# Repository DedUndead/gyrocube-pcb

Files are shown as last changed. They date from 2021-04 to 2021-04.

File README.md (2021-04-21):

# Gyrocube PCB design

Project is ongoing.

## Concept description 

GyroCube is a Smart-Home accessory. The GyroCube is a multipurpose cube that can perform different functions based on the cube placing. The functionality is changed by simply flipping the cube on the table. The functionalities are humidity measurements, OMA notifications, and weather-forecasts. GyroCube uses vibration modules and LEDs as the output method to notify the user of changes.<br><br>
GyroCube consists of the main station and cubes that will be in constant M2M communication. The main station handles the sensor measurements and internet communications, while the cubes react to changes in the main station. Thus, allowing the GyroCube environment to be scalable, as the user can connect as many cubes as he wants. 
The goal is to provide the user with a delightful-looking home accessory, which will also allow them to obtain helpful information in a simple, minimalistic way. 

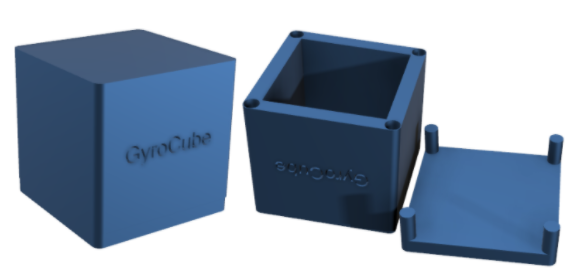
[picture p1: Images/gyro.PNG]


## Topology example - Star

The HUB acts as Zigbee coordinator/router, while the cubes are end devices of the topology. HUB communicates with Wireless Access Point.

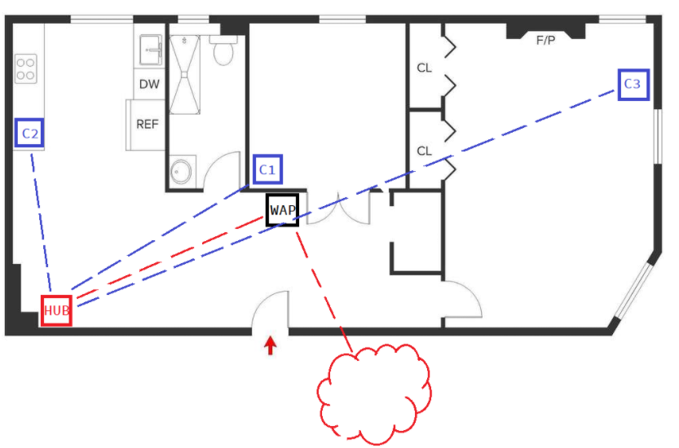
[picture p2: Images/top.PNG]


## PCB design description

PCB design for the gyrocube IoT project. Consists of several parts: x6 RGB LED PCBs, cube's MCU and main hub's MCU.
External components were used when designing the schematics

<b>Hub PCB</b>:<br>
[Microcontroller](https://app.ultralibrarian.com/details/23afb9f1-10a0-11e9-ab3a-0a3560a4cccc/Microchip/PIC32MX575F512H-80I-PT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)<br>
[RF Tranciever (Zigbee)](https://app.ultralibrarian.com/details/42fe3879-10a0-11e9-ab3a-0a3560a4cccc/Microchip/AT86RF231-ZU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)<br>
[Wi-Fi Module](https://app.ultralibrarian.com/details/2b6afdaf-b24e-11ea-b5d0-0aebb021a1ea/Silicon-Labs/WFM200S022XNA2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)

<b>Cube MCU</b>:<br>
[Microcontroller](https://app.ultralibrarian.com/details/4b4afbe8-2e28-11eb-9033-0a34d6323d74/Microchip/PIC18F47K40-I-P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)<br>
[Gyroscope](https://app.ultralibrarian.com/details/68dbfc0c-1e52-11eb-9033-0a34d6323d74/STMicroelectronics/L3GD20H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)<br>
Humidity/Temperature sensor is custom. The library is cached in the respective folder.<br>
[Vibration coin](https://www.snapeda.com/parts/C0720B001F/Jinlong%20Machinery%20&amp;%20Electronics,%20Inc./view-part/)

## LED PCB design:

Uses ws2812b-5050 LED and 100-1000 uF filtering capacitor. The exact value is not yet specified.

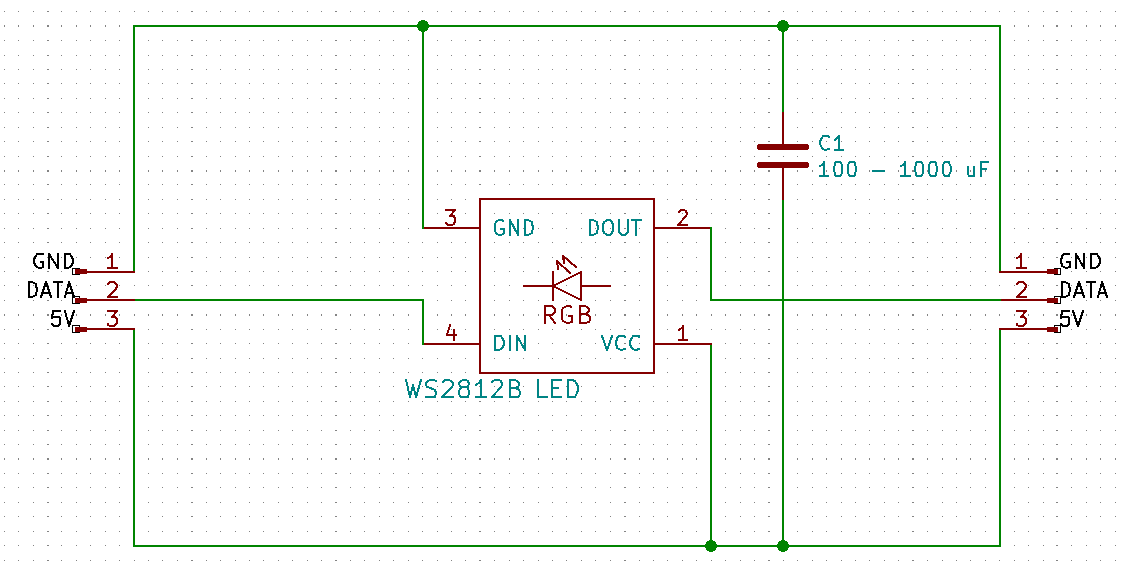
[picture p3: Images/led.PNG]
LED PCB


The LED PCB are connected to each other with wires. The cube's PCB contains the connector to connect the first LED, that starts the series.

Connector

## Cube PCB design:

Cube PCB contains the MCU and all the peripherals.

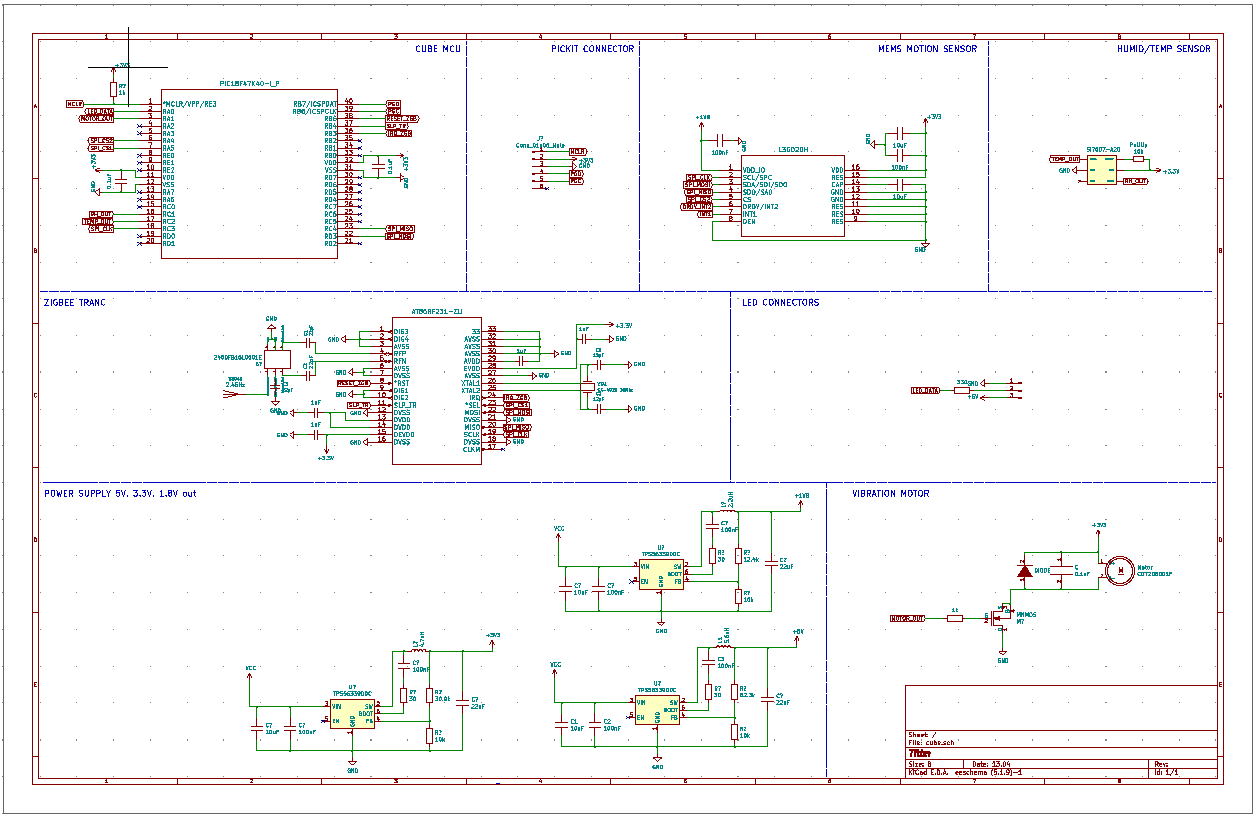
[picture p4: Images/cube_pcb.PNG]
Cube PCB


### Cube MCU: PIC18F47K40-I/P

The MCU consists of several connection "zones": 

* SPI communication with 2 chip select slave pins 
* MCLR/PDG/PGC + Connector for PICKit programmability
* Decoupling 0.1uF capacitors
* Peripheral control pins (PWM, sleep/wake up/reset signals)

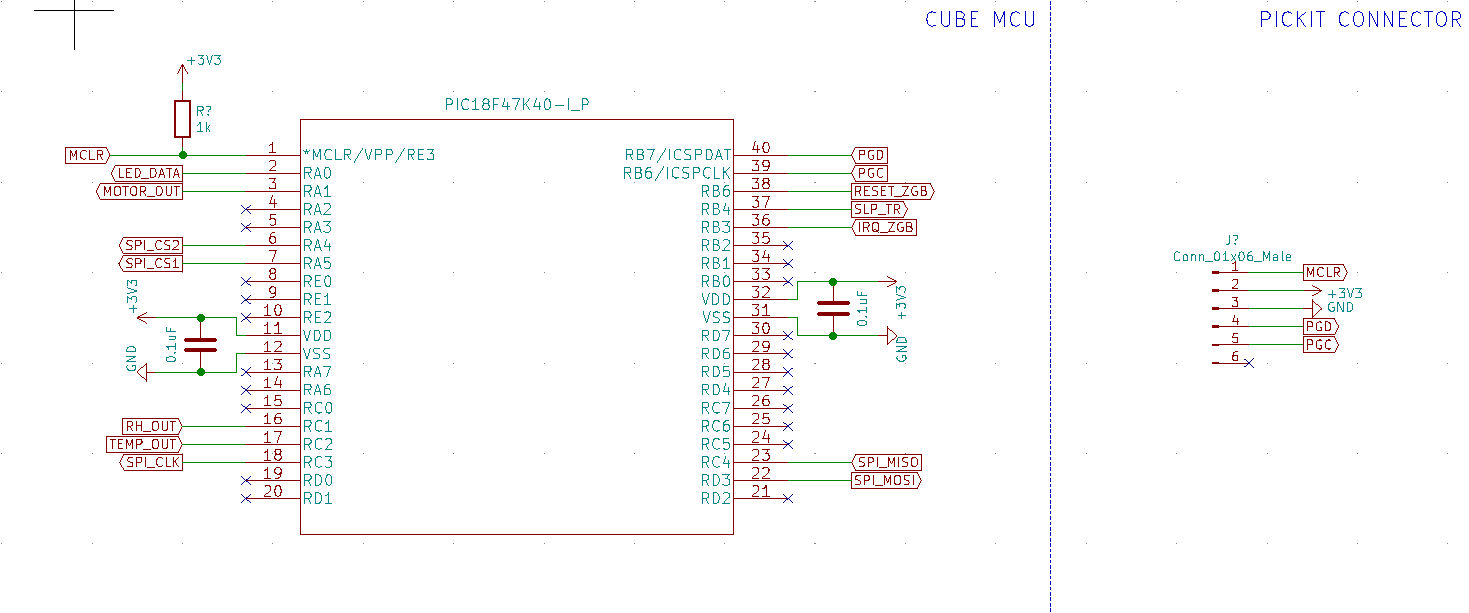
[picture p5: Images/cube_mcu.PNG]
Cube MCU


### Gyroscope and Temp/Hum sensor

MEMS Motion sensor: L3GD20H, three-axis gyroscope, utilizes SPI interface<br>
Humidity/Temperature  sensor: Si7007-A20, digital output via PWM

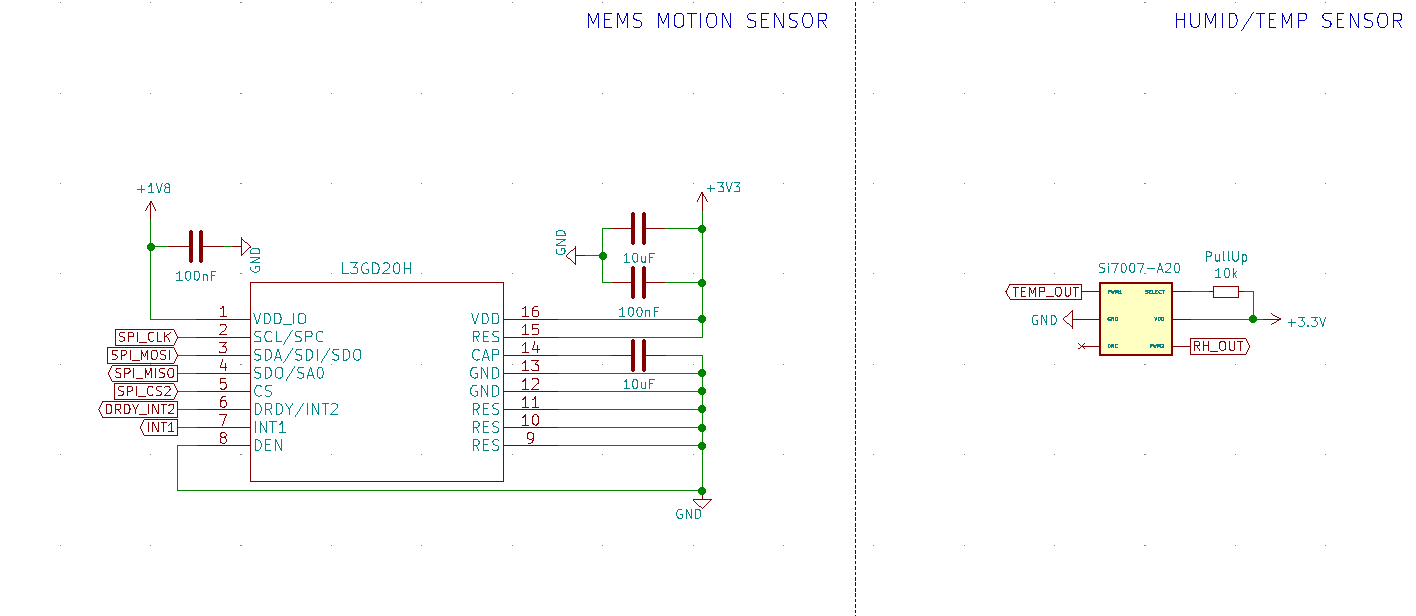
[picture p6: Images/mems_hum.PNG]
MEMS Motion and Temp


### Vibration motor

Diode and capacitor protect the components from voltage spikes, generated by the motor.<br>
Motor requires 75 mA, N-Channel MOSFET amplifies the current from MCU's GPIO.<br>
Intensity of vibration is handeled by PWM.

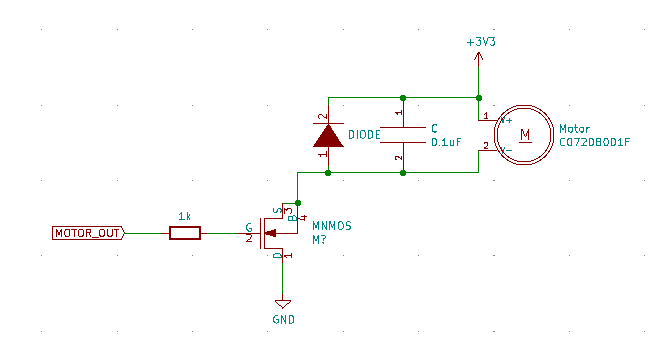
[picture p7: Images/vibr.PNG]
Vibration motor


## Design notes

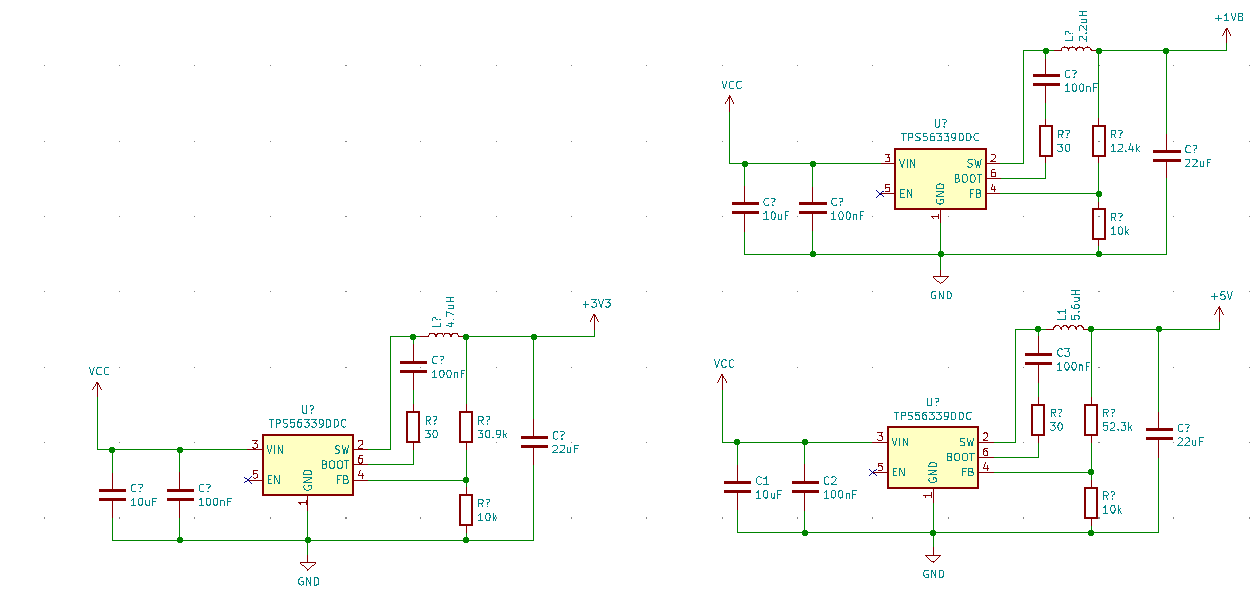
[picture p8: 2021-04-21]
Images/power_supply.PNG

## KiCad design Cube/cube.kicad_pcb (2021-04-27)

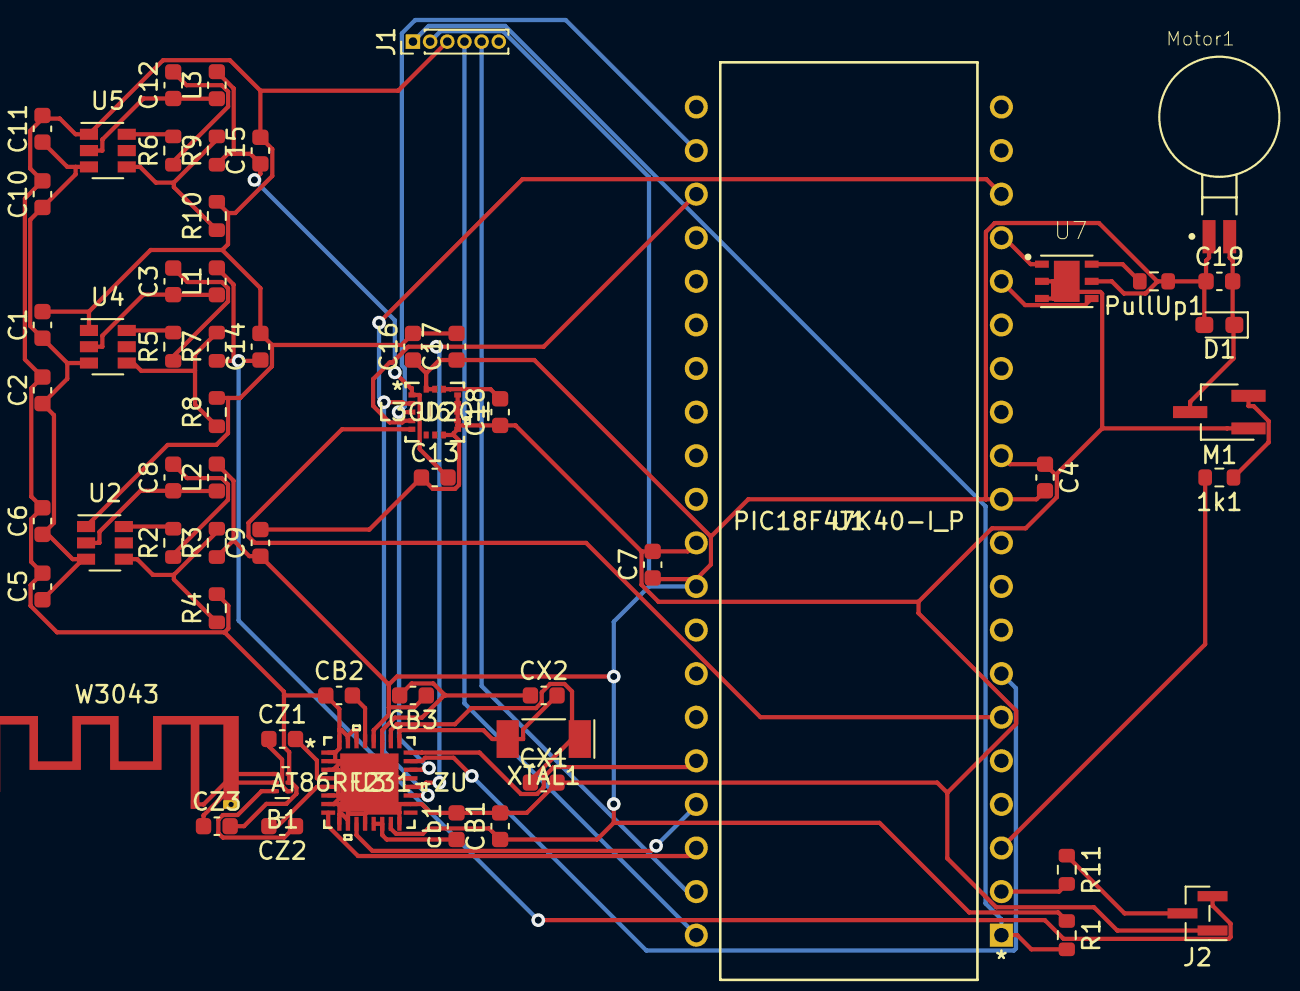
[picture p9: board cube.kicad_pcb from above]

Board: 2 copper layers, 59 parts (0 on the bottom side), 47 nets.

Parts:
1k1: R; R_0603_1608Metric
B1: 2450FB15L0001E; Balun_Johanson_1.6x0.8mm
C1, C5, C10, C16, C18: 10uF; C_0603_1608Metric
C2, C3, C6, C8, C11, C12, C13, C17: 100nF; C_0603_1608Metric
C4, C7, C19: 0.1uF; C_0603_1608Metric
C9, C14, C15: 22uF; C_0603_1608Metric
CB1, CB2, CB3: 1uF; C_0603_1608Metric
CX1, CX2: 12pF; C_0603_1608Metric
CZ1, CZ2, CZ3: 22pF; C_0603_1608Metric
D1: DIODE; D_0603_1608Metric_Pad1.05x0.95mm_HandSolder
J1: Conn_01x06_Male; PinHeader_1x06_P1.00mm_Vertical
J2: Conn_01x03_Male; PinHeader_1x03_P1.00mm_Vertical_SMD_Pin1Left
L1: 5.6uH; L_0603_1608Metric
L2: 4.7uH; L_0603_1608Metric
L3: 2.2uH; L_0603_1608Metric
M1: MNMOS; SOT-23W_Handsoldering
Motor1: C0720B001F; XDCR_C0720B001F
PullUp1: 10k; R_0603_1608Metric
R1: 1k; R_0603_1608Metric
R2, R5, R6: 30; R_0603_1608Metric
R3: 30.9k; R_0603_1608Metric
R4, R8, R10: 10k; R_0603_1608Metric
R7: 52.3k; R_0603_1608Metric
R9: 12.4k; R_0603_1608Metric
R11: 330; R_0603_1608Metric
U1: PIC18F47K40-I_P; PIC18F47K40-I&slash_P
U2, U4, U5: TPS56339DDC; SOT-23-6
U3: AT86RF231-ZU
U6: L3GD20H
U7: Si7007-A20; SON100P300X300X80-7N
W3043: 2.4GHz; Texas_SWRA117D_2.4GHz_Left
XTAL1: CX-4025 16Mhz; Crystal_SMD_MicroCrystal_CC4V-T1A-2Pin_5.0x1.9mm
cb1: 1uF; C_0603_1608Metric

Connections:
+1V8: C13.2, C15.1, L3.2, R9.1, U6.1
+3V3: C4.2, C7.1, C9.1, C16.1, C17.1, C19.1, CB1.1, CB3.1, D1.2, J1.2, L2.2, Motor1.1, PullUp1.1, R1.1, R3.1, U1.11, U1.32, U3.15, U3.28, U6.15, U6.16, U7.5
+5V: C14.1, J2.3, L1.2, R7.1
GND: B1.5, B1.6, C1.2, C2.2, C4.1, C5.2, C6.2, C7.2, C9.2, C10.2, C11.2, C13.1, C14.2, C15.2, C16.2, C17.2, C18.1, CB1.2, CB2.1, CB3.2, CX1.2, CX2.1, CZ3.2, J1.3, J2.1, M1.1, R4.2, R8.2, R10.2, U1.12, U1.31, U2.1, U3.1, U3.2, U3.3, U3.6, U3.7, U3.9, U3.10, U3.12, U3.16, U3.18, U3.21, U3.27, U3.30, U3.31, U3.32, U3.33, U4.1, U5.1, U6.8, U6.9, U6.10, U6.11, U6.12, U6.13, U7.2, U7.3, U7.7, cb1.2
IRQ_ZGB: U1.36, U3.24
LED_DATA: R11.2, U1.2
MCLR: J1.1, R1.2, U1.1
MOTOR_OUT: 1k1.2, U1.3
unnamed: 1k1.1, M1.2
unnamed: B1.1, W3043.1
unnamed: B1.2, CZ3.1
unnamed: B1.3, CZ2.1
unnamed: B1.4, CZ1.1
unnamed: C3.1, L1.1, U4.2
unnamed: C3.2, R5.1
unnamed: C8.1, L2.1, U2.2
unnamed: C8.2, R2.1
unnamed: C12.1, L3.1, U5.2
unnamed: C12.2, R6.1
unnamed: C18.2, U6.14
unnamed: C19.2, D1.1, M1.3, Motor1.2
unnamed: CB2.2, U3.29
unnamed: CX1.1, U3.26, XTAL1.1
unnamed: CX2.2, U3.25, XTAL1.2
unnamed: CZ1.2, U3.4
unnamed: CZ2.2, U3.5
unnamed: J2.2, R11.1
unnamed: PullUp1.2, U7.6
unnamed: R2.2, U2.6
unnamed: R3.2, R4.1, U2.4
unnamed: R5.2, U4.6
unnamed: R6.2, U5.6
unnamed: R7.2, R8.1, U4.4
unnamed: R9.2, R10.1, U5.4
unnamed: U3.13, U3.14, cb1.1
PGC: J1.5, U1.39
PGD: J1.4, U1.40
RESET_ZGB: U1.38, U3.8
RH_OUT: U1.16, U7.4
SLP_TR: U1.37, U3.11
SPI_CLK: U1.18, U3.19, U6.2
SPI_CS1: U1.7, U3.23
SPI_CS2: U1.6, U6.5
SPI_MISO: U1.23, U3.20, U6.4
SPI_MOSI: U1.22, U3.22, U6.3
TEMP_OUT: U1.17, U7.1
VCC: C1.1, C2.1, C5.1, C6.1, C10.1, C11.1, U2.3, U4.3, U5.3

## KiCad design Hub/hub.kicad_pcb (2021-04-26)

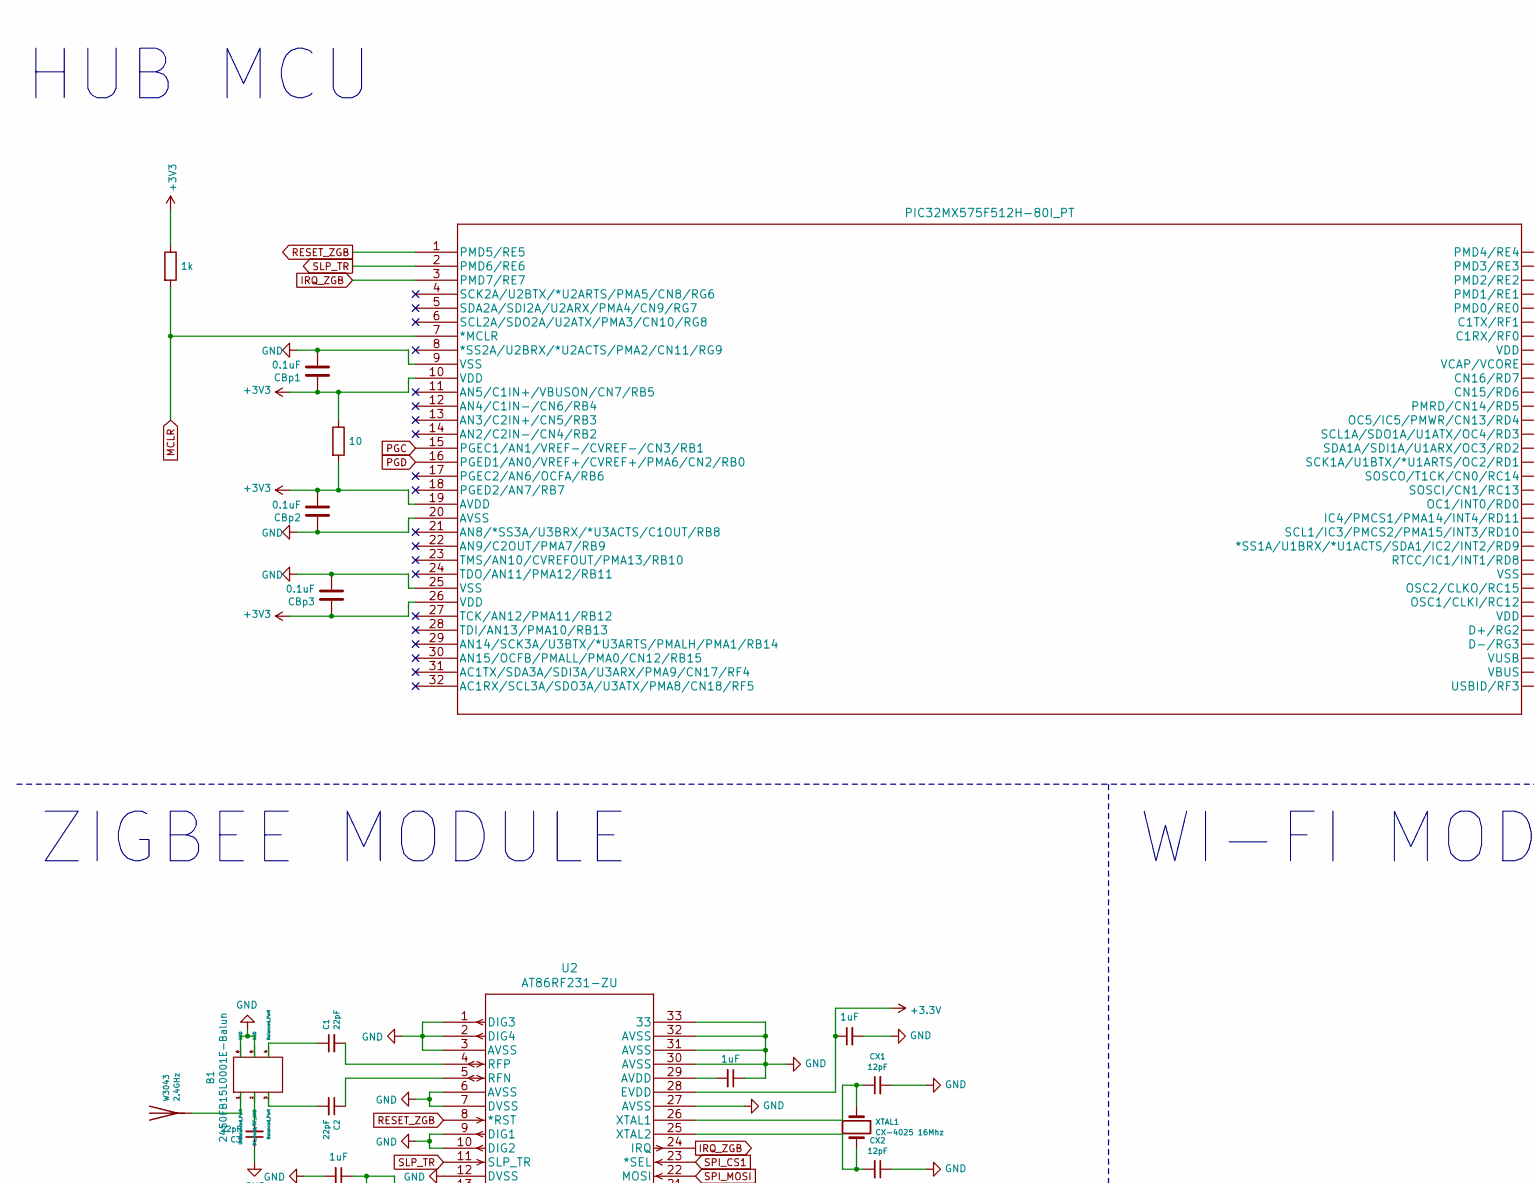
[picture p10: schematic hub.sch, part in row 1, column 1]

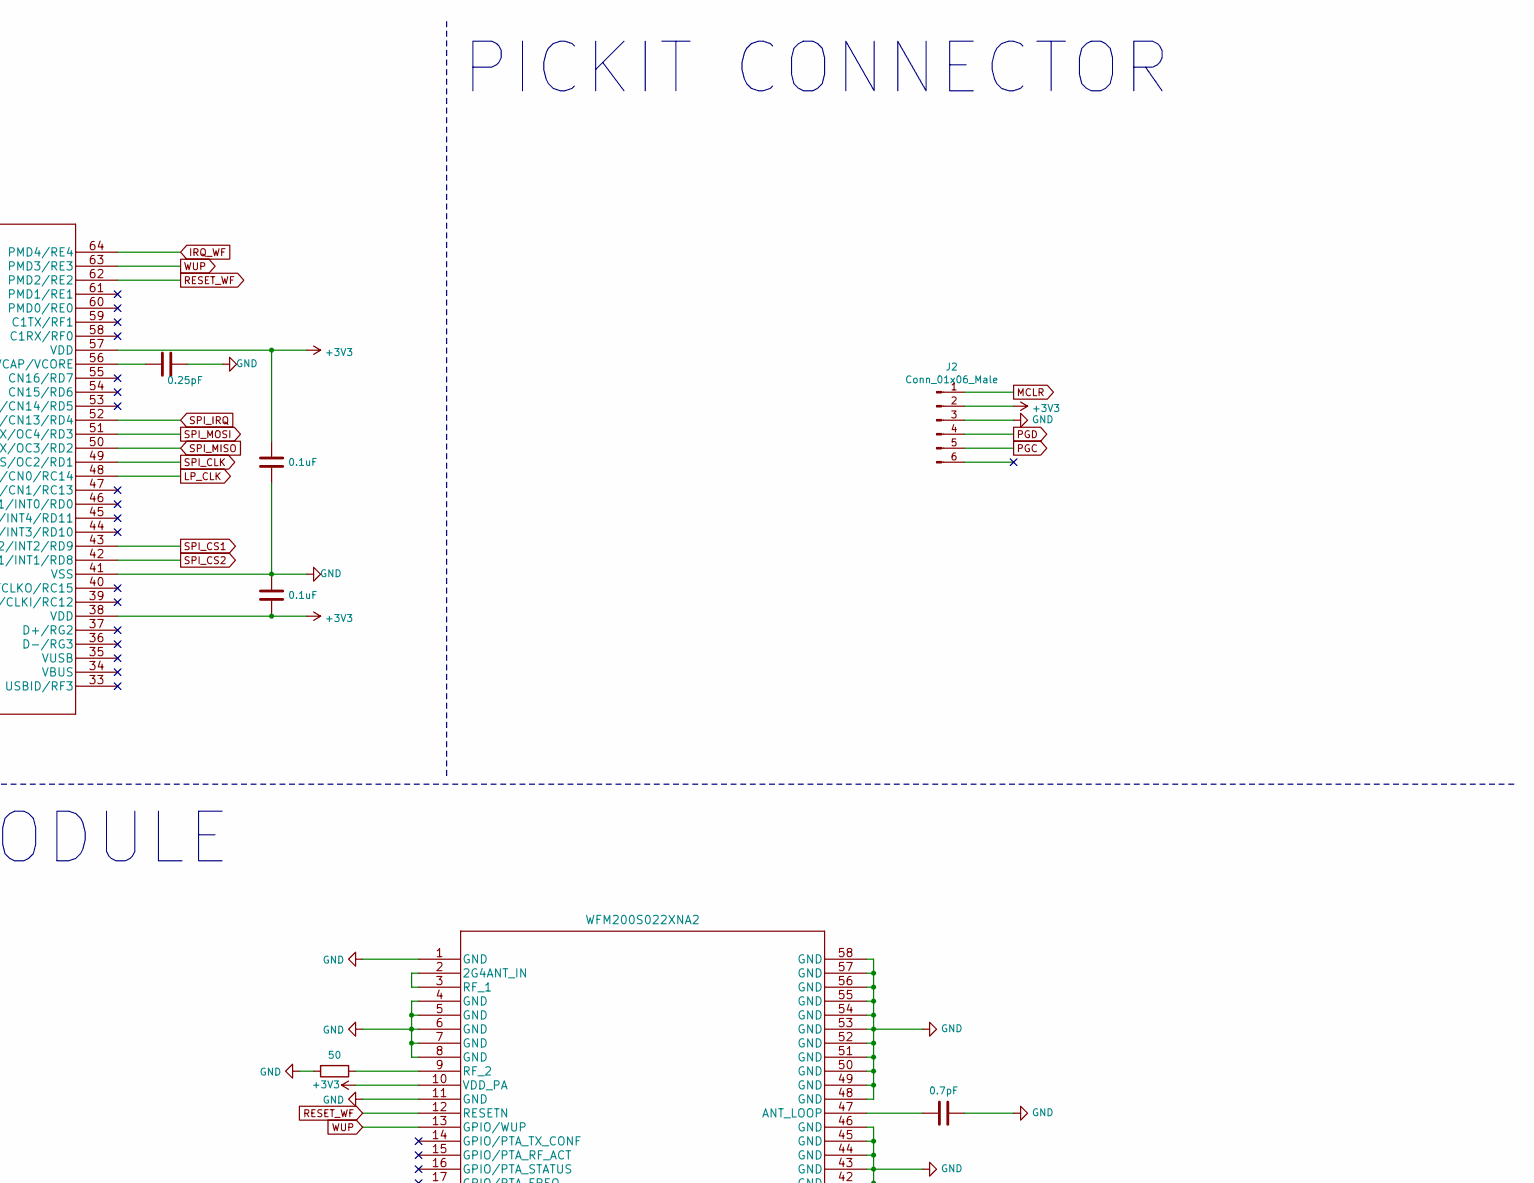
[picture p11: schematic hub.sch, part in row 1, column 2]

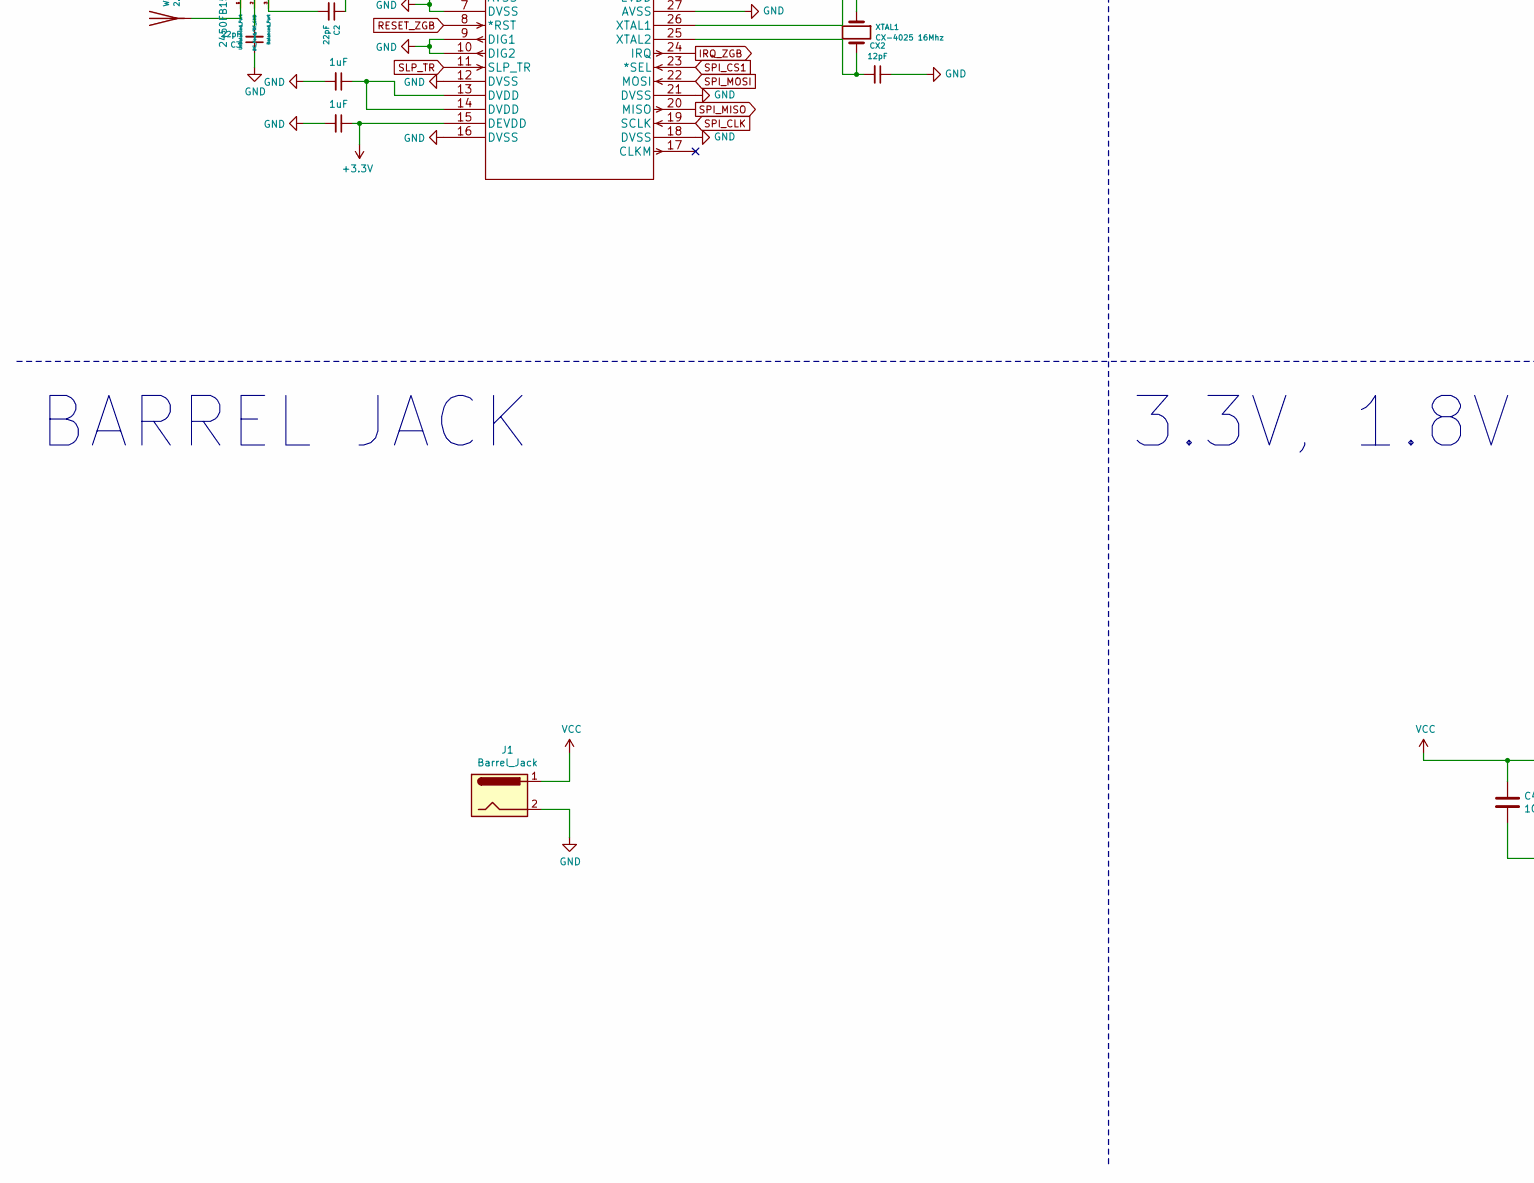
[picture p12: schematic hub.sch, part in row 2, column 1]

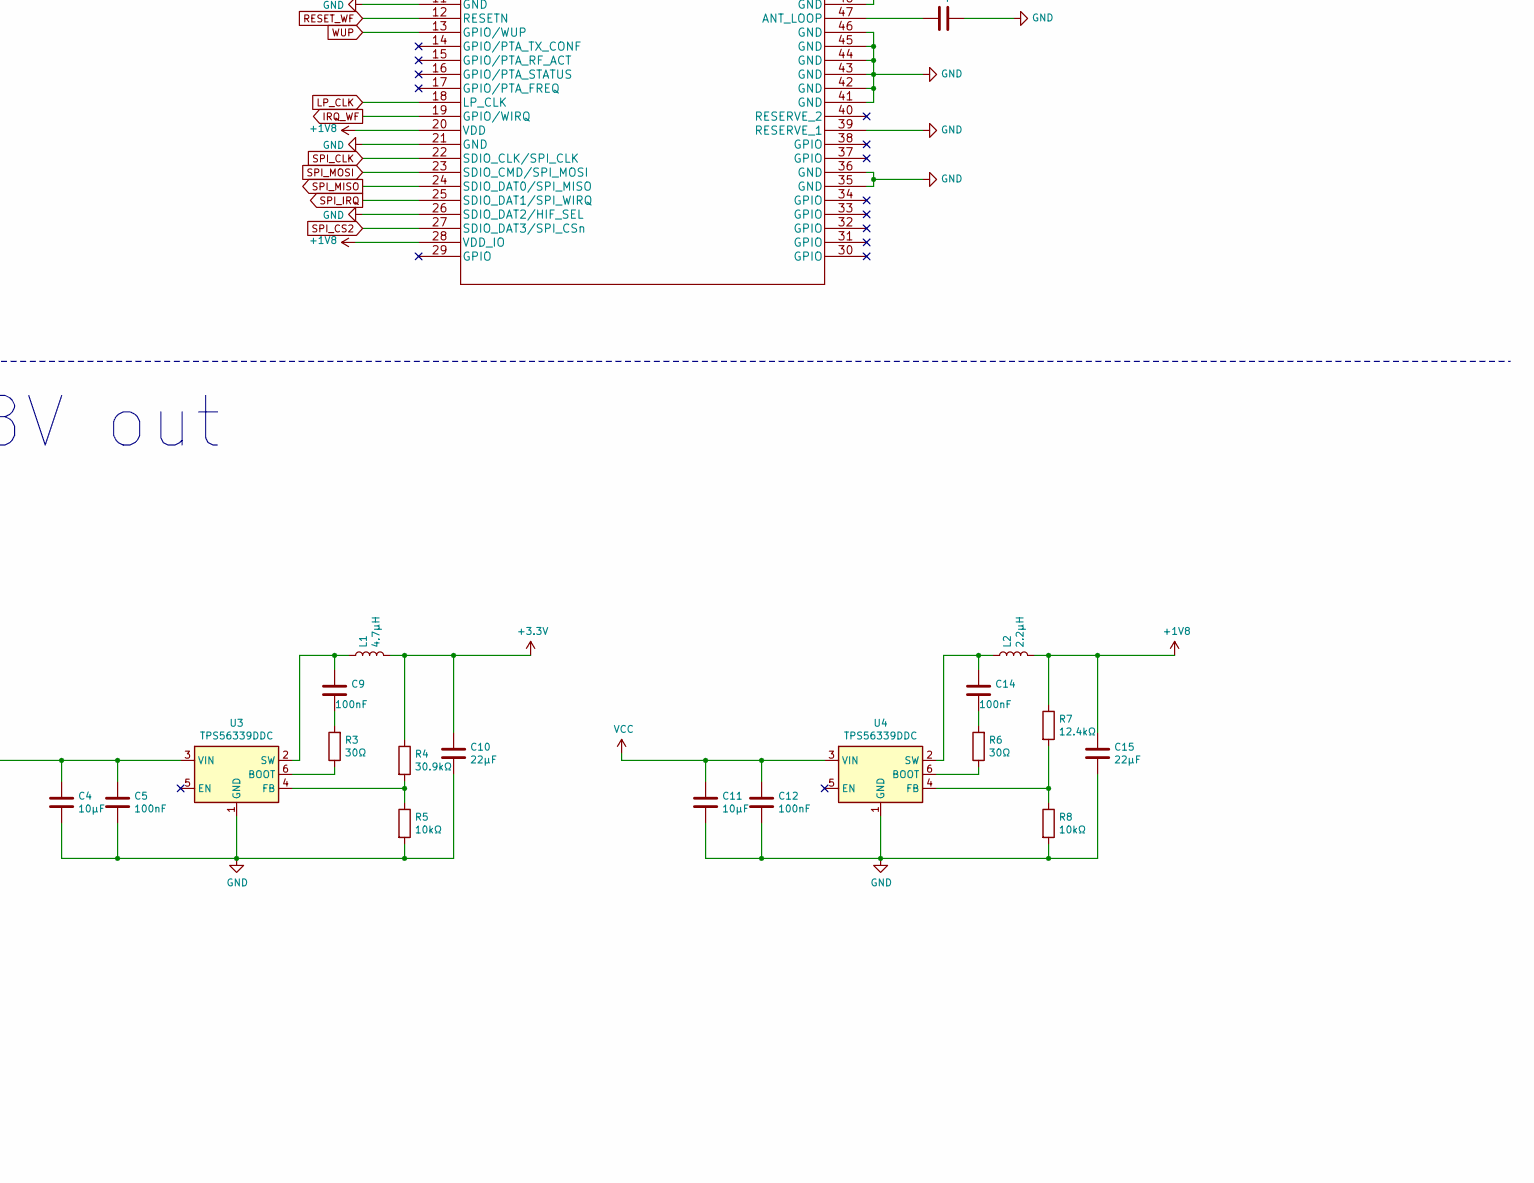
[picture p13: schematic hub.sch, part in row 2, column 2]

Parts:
B1: 2450FB15L0001E-Balun; Balun_Johanson_1.6x0.8mm
C1, C2, C3: 22pF; C_0603_1608Metric
C4, C11: 10µF; C_0603_1608Metric
C5, C9, C12, C14: 100nF; C_0603_1608Metric
C6: 0.25pF; C_0603_1608Metric
C7, C8: 0.1uF; C_0603_1608Metric
C10, C15: 22µF; C_0603_1608Metric
C13: 0.7pF; C_0603_1608Metric
CB1, CB2, CB3: 1uF; C_0603_1608Metric
CBp1, CBp2, CBp3: 0.1uF; C_0603_1608Metric
CX1, CX2: 12pF; C_0603_1608Metric
J1: Barrel_Jack; BarrelJack_CUI_PJ-063AH_Horizontal
J2: Conn_01x06_Male; PinHeader_1x06_P1.00mm_Vertical
L1: 4.7µH; L_0603_1608Metric
L2: 2.2µH; L_0603_1608Metric
R1: 1k; R_0603_1608Metric
R2: 50; R_0603_1608Metric
R3, R6: 30Ω; R_0603_1608Metric
R4: 30.9kΩ; R_0603_1608Metric
R5, R8: 10kΩ; R_0603_1608Metric
R7: 12.4kΩ; R_0603_1608Metric
RR1: 10; R_0603_1608Metric
U1: PIC32MX575F512H-80I_PT; PIC32MX575F512H-80I&slash_PT
U2: AT86RF231-ZU
U3, U4: TPS56339DDC; SOT-23-6
W3043: 2.4GHz; Texas_SWRA117D_2.4GHz_Left
WiFi1: WFM200S022XNA2
XTAL1: CX-4025 16Mhz; Crystal_SMD_MicroCrystal_CC4V-T1A-2Pin_5.0x1.9mm
cb1: 1uF; C_0603_1608Metric

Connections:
+1V8: C15.1, L2.2, R7.1, WiFi1.20 (VDD), WiFi1.28 (VDD_IO)
GND: B1.5 (GND), B1.6 (GND), C3.1, C4.2, C5.2, C6.1, C7.2, C8.1, C10.2, C11.2, C12.2, C13.1, C15.2, CB1.2, CB2.1, CB3.2, CBp1.2, CBp2.1, CBp3.2, CX1.2, CX2.1, J1.2, J2.3, R2.2, R5.2, R8.2, U1.9 (VSS), U1.20 (AVSS), U1.25 (VSS), U1.41 (VSS), U2.1 (DIG3), U2.2 (DIG4), U2.3 (AVSS), U2.6 (AVSS), U2.7 (DVSS), U2.9 (DIG1), U2.10 (DIG2), U2.12 (DVSS), U2.16 (DVSS), U2.18 (DVSS), U2.21 (DVSS), U2.27 (AVSS), U2.30 (AVSS), U2.31 (AVSS), U2.32 (AVSS), U2.33, U3.1 (GND), U4.1 (GND), WiFi1.1 (GND), WiFi1.4 (GND), WiFi1.5 (GND), WiFi1.6 (GND), WiFi1.7 (GND), WiFi1.8 (GND), WiFi1.11 (GND), WiFi1.21 (GND), WiFi1.26 (SDIO_DAT2/HIF_SEL), WiFi1.35 (GND), WiFi1.36 (GND), WiFi1.39 (RESERVE_1), WiFi1.41 (GND), WiFi1.42 (GND), WiFi1.43 (GND), WiFi1.44 (GND), WiFi1.45 (GND), WiFi1.46 (GND), WiFi1.48 (GND), WiFi1.49 (GND), WiFi1.50 (GND), WiFi1.51 (GND), WiFi1.52 (GND), WiFi1.53 (GND), WiFi1.54 (GND), WiFi1.55 (GND), WiFi1.56 (GND), WiFi1.57 (GND), WiFi1.58 (GND), cb1.2
IRQ_WF: U1.64 (PMD4/RE4), WiFi1.19 (GPIO/WIRQ)
IRQ_ZGB: U1.3 (PMD7/RE7), U2.24 (IRQ)
LP_CLK: U1.48 (SOSCO/T1CK/CN0/RC14), WiFi1.18 (LP_CLK)
MCLR: J2.1, R1.2, U1.7 (*MCLR)
unnamed: B1.1 (Unbalanced_Port), W3043.1
unnamed: B1.2 (DC_Feed/RF_GND), C3.2
unnamed: B1.3 (Balanced_Port), C2.2
unnamed: B1.4 (Balanced_Port), C1.1
unnamed: C1.2, U2.4 (RFP)
unnamed: C2.1, U2.5 (RFN)
unnamed: C6.2, U1.56 (VCAP/VCORE)
unnamed: C9.1, L1.1, U3.2 (SW)
unnamed: C9.2, R3.2
unnamed: C13.2, WiFi1.47 (ANT_LOOP)
unnamed: C14.1, L2.1, U4.2 (SW)
unnamed: C14.2, R6.2
unnamed: CB2.2, U2.29 (AVDD)
unnamed: CX1.1, U2.26 (XTAL1), XTAL1.1
unnamed: CX2.2, U2.25 (XTAL2), XTAL1.2
unnamed: R2.1, WiFi1.9 (RF_2)
unnamed: R3.1, U3.6 (BOOT)
unnamed: R4.2, R5.1, U3.4 (FB)
unnamed: R6.1, U4.6 (BOOT)
unnamed: R7.2, R8.1, U4.4 (FB)
unnamed: U2.13 (DVDD), U2.14 (DVDD), cb1.1
unnamed: WiFi1.2 (2G4ANT_IN), WiFi1.3 (RF_1)
PGC: J2.5, U1.15 (PGEC1/AN1/VREF-/CVREF-/CN3/RB1)
PGD: J2.4, U1.16 (PGED1/AN0/VREF+/CVREF+/PMA6/CN2/RB0)
RESET_WF: U1.62 (PMD2/RE2), WiFi1.12 (RESETN)
RESET_ZGB: U1.1 (PMD5/RE5), U2.8 (*RST)
SLP_TR: U1.2 (PMD6/RE6), U2.11 (SLP_TR)
SPI_CLK: U1.49 (SCK1A/U1BTX/*U1ARTS/OC2/RD1), U2.19 (SCLK), WiFi1.22 (SDIO_CLK/SPI_CLK)
SPI_CS1: U1.43 (*SS1A/U1BRX/*U1ACTS/SDA1/IC2/INT2/RD9), U2.23 (*SEL)
SPI_CS2: U1.42 (RTCC/IC1/INT1/RD8), WiFi1.27 (SDIO_DAT3/SPI_CSn)
SPI_IRQ: U1.52 (OC5/IC5/PMWR/CN13/RD4), WiFi1.25 (SDIO_DAT1/SPI_WIRQ)
SPI_MISO: U1.50 (SDA1A/SDI1A/U1ARX/OC3/RD2), U2.20 (MISO), WiFi1.24 (SDIO_DAT0/SPI_MISO)
SPI_MOSI: U1.51 (SCL1A/SDO1A/U1ATX/OC4/RD3), U2.22 (MOSI), WiFi1.23 (SDIO_CMD/SPI_MOSI)
VCC: C4.1, C5.1, C11.1, C12.1, J1.1, U3.3 (VIN), U4.3 (VIN)
WUP: U1.63 (PMD3/RE3), WiFi1.13 (GPIO/WUP)

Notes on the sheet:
ZIGBEE MODULE
HUB MCU
WI-FI MODULE
BARREL JACK
3.3V, 1.8V out
PICKIT CONNECTOR

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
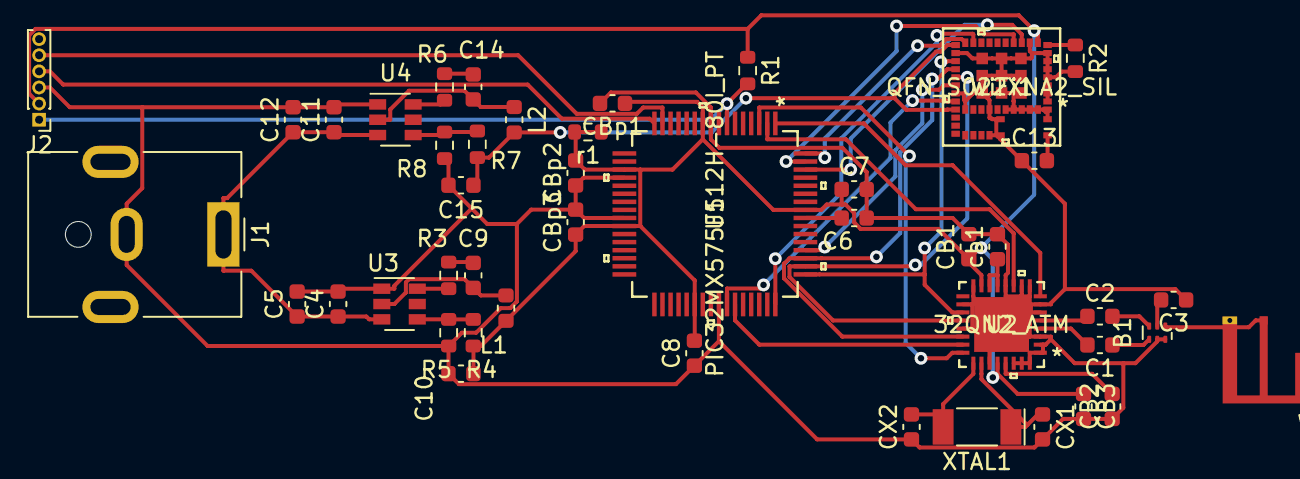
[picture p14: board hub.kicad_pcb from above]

Board: 2 copper layers, 45 parts (0 on the bottom side), 42 nets.

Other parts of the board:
r1: 10; R_0603_1608Metric

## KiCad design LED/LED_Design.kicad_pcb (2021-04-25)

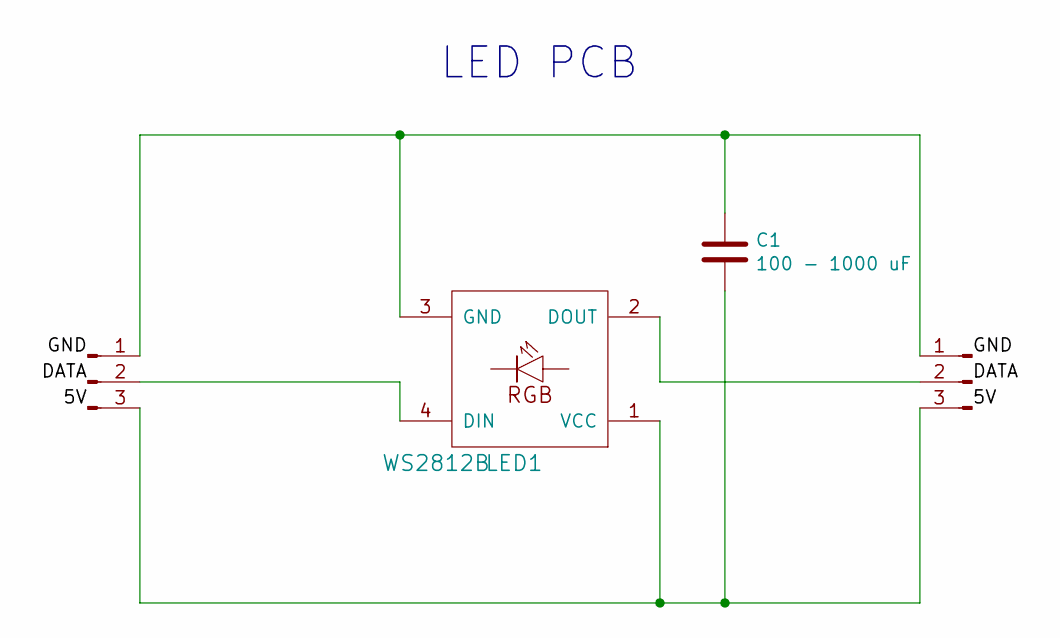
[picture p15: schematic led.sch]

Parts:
C1: 100 - 1000 uF; C_0603_1608Metric
J1, J2: Conn_01x03_Male; SolderWire-0.1sqmm_1x03_P3.6mm_D0.4mm_OD1mm
LED1: WS2812B; LED_WS2812B_PLCC4_5.0x5.0mm_P3.2mm

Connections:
unnamed: C1.1, J1.1, J2.1, LED1.3 (GND)
unnamed: C1.2, J1.3, J2.3, LED1.1 (VCC)
unnamed: J1.2, LED1.4 (DIN)
unnamed: J2.2, LED1.2 (DOUT)

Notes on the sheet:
LED PCB

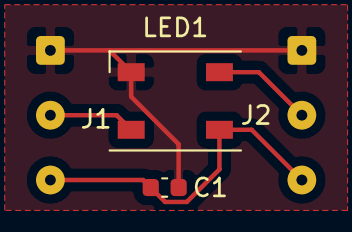
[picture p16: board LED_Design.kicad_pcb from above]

Board: 2 copper layers, 4 parts (0 on the bottom side), 4 nets.

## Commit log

2021-04-13 Add separate sheet for each contributor
    [Alex.sch, Daniel.sch, Pavel.sch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]
2021-04-16 Add LED PCB design
    [Alex.sch, Daniel.sch, Pavel.sch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]
2021-04-18 changed led capacitor value
    [led.sch]
2021-04-18 updated led schematic
    [led.sch]
2021-04-18 Add HUB PCB schema
    [Daniel.sch, cube.sch, hub.sch]
2021-04-19 Edit HUB PCB
    [hub.sch, pcb.sch]
2021-04-19 Finish hub pcb schema
    [hub.sch]
2021-04-19 Add cube PCB design
    [cube.sch, hub.sch]
2021-04-19 project structure change
    [cube.sch, hub.sch, led.sch]
2021-04-19 Added humidity/gyro sensors to the cube pcb
    [cube.sch]
2021-04-19 Edit cube pcb style
    [cube.sch]
2021-04-20 Finish LED scematics
    [cube.sch, led.sch]
2021-04-20 Add minor changes
    [cube.sch]
2021-04-20 Update
    Zigbee update:
    - Added custom made symbol: SMD Balun - 2450FB15L0001E
    - Added Antenna - Ceramic chip: W3043
    Note: There might be a missing capacitor in the communication between the antenna to the Balun - some circuit reference does have it some doesn't
    [cube.sch, hub.sch]
2021-04-20 Add motor to the cube schematics
    [cube.sch, hub.sch]
2021-04-20 added power
2021-04-20 fixed power circuit
    [cube.sch]
2021-04-20 Add power supply changes
    [cube.sch, hub.sch]
2021-04-20 added both voltages to the hub
    [hub.sch]
2021-04-20 Add programmable connectors
    [cube.sch, hub.sch]
2021-04-21 Fix minor mistakes after the presentation
    [cube.sch, led.sch]
2021-04-25 hub pcb stuck
    [LED_Design.kicad_pcb, cube.sch, hub.kicad_pcb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]
2021-04-26 hub pcb routed
    [hub.kicad_pcb]
2021-04-26 Add components to cube
    [cube.sch]
2021-04-27 Add cube pcb layout
    [cube.kicad_pcb, cube.sch]
2021-04-27 added cube routes
    [cube.kicad_pcb]

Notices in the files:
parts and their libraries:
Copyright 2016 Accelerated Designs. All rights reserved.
